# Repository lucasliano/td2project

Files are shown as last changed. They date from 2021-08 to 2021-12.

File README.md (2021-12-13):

<!-- Badged -->





> :warning: **Work In Progress** :warning:

<!-- PROJECT LOGO -->
<br />
<p align="center">
  <a href="https://github.com/lucasliano/td2project">
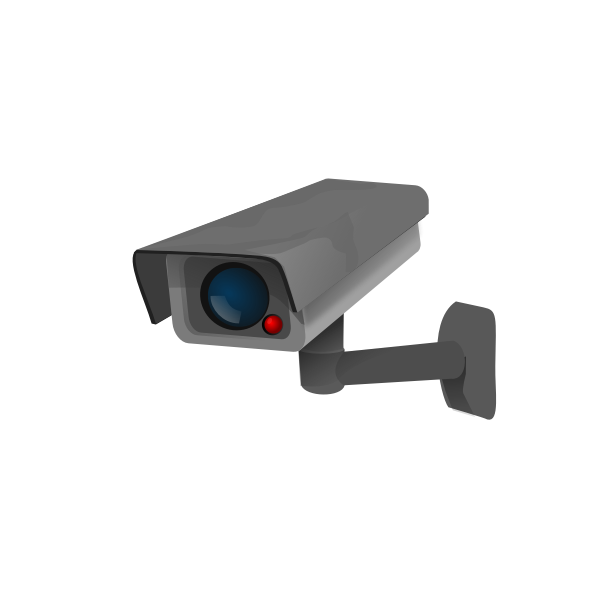
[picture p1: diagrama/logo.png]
    
  </a>

  <h3 align="center">Security Alarm System</h3>
  
  <p align="center">
    This security system project is the final assignment of the digital technics II subjects at Universidad Tecnológica Nacional.
    <br />
    <a href="https://github.com/lucasliano/td2project"><strong>Explore the docs »</strong></a>
    <br />
    <br />
    <a href="https://github.com/lucasliano/td2project">View Demo</a>
    ·
    <a href="https://github.com/lucasliano/td2project/issues">Report Bug</a>
    ·
    <a href="https://github.com/lucasliano/td2project/issues">Request Feature</a>
  </p>
</p>

<!-- TABLE OF CONTENTS -->
<details open="open">
  <summary><h2 style="display: inline-block">Table of Contents</h2></summary>
  <ol>
    <li>
      <a href="#about-the-project">About The Project</a>
      <ol>
      <li><a href="#system-diagram">System Diagram</a></li>
      <li><a href="#main-board-pcb-and-schematics">Main Board PCB and Schematics</a></li>
      <li><a href="#equipment">Equipment</a></li>
    </ol>
    </li>
    <li><a href="#authors">Authors</a></li>
    <li><a href="#license">License</a></li>
    <li><a href="#contact">Contact</a></li>
  </ol>
</details>

## About The Project

The main idea of this project is to build a systems which allows you to detect motion in different zones within your home.  

The activation/deactivation of the system is meant to be controlled using an android app or directly trough the front keyboard. At the same time, it would be possible to configure the system to deactivate the alarm in presence of a known RFID card.

Should an error occurred, a notification will be sent to the mobile device and it will be logged into the internal EEPROM memory. The system also takes into account possible disconnections from the power supply. 

#### System Diagram
<p align="center">
  <a href="https://github.com/lucasliano/td2project">
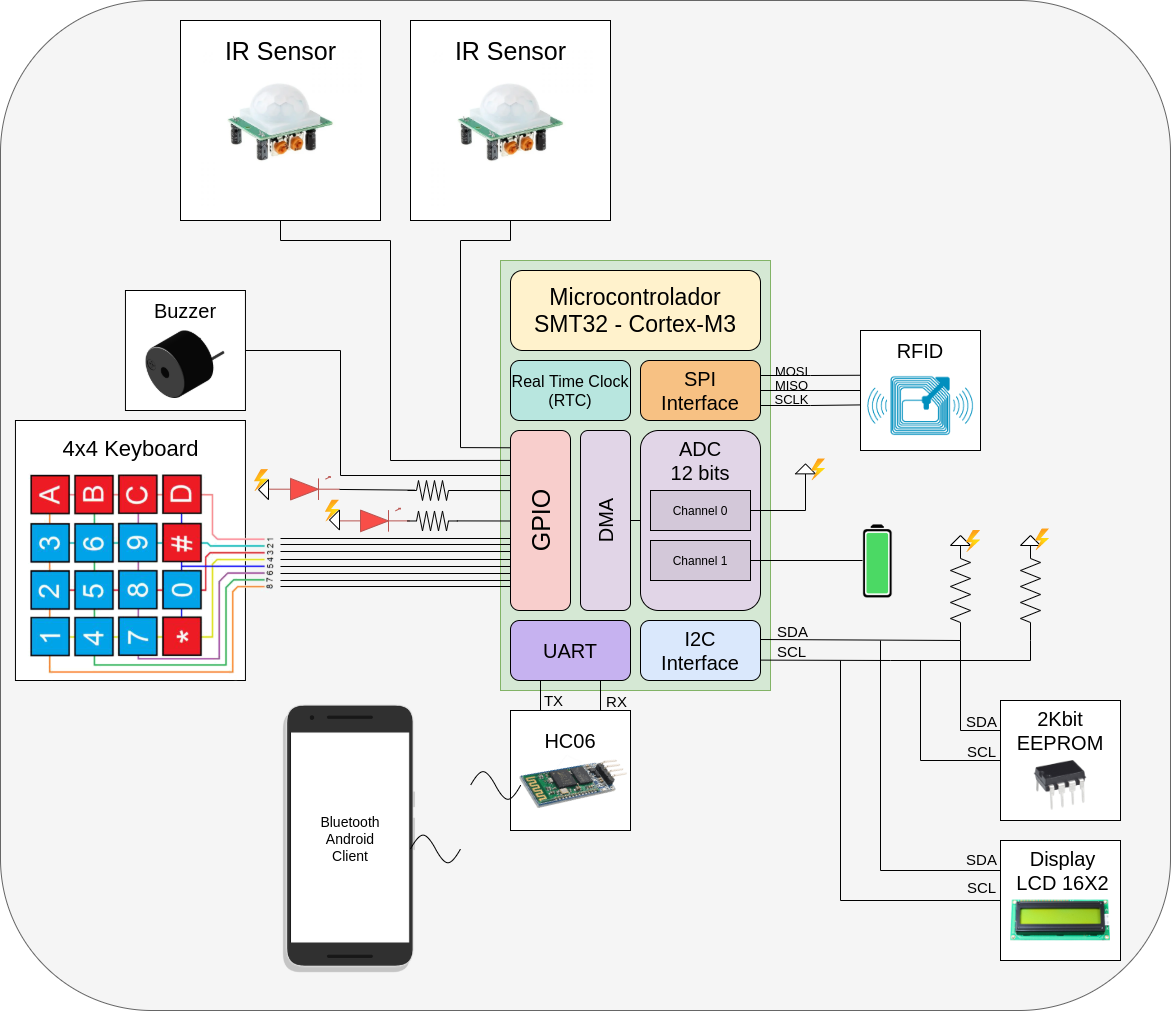
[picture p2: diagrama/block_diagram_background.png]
Diagram
    
  </a>
</p>

#### Memory Map
This section describes the EEPROM memory organization. Each section provides critical information to the system. All the registers stored in the _Logs Block_ will be available through the android app.

<p align="center">
  <a href="https://github.com/lucasliano/td2project">
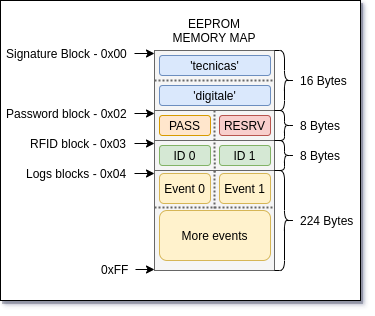
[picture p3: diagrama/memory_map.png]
Memory map
    
  </a>
</p>

### Main Board PCB and Schematics

#### Schematics
The main board includes a battery charger and power supply source administrator. You will find this schematic in a PDF file in the ``` PCB_files_kicad ``` folder.

<p align="center">
  <a href="https://github.com/lucasliano/td2project/blob/main/PCB/Schematic%20v1.7.pdf">
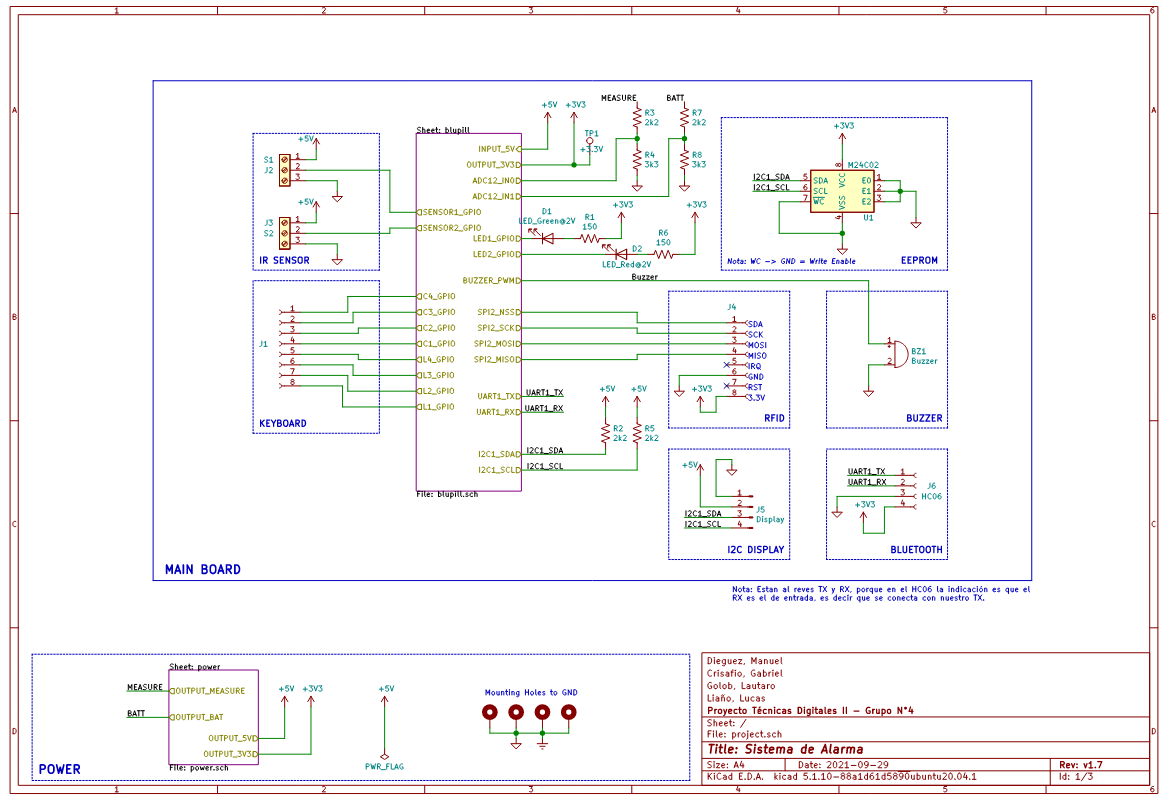
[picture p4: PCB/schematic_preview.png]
Schematic
    
  </a>
</p>

#### PCB
<p align="center">
  <a href="https://github.com/lucasliano/td2project/tree/main/PCB/project">
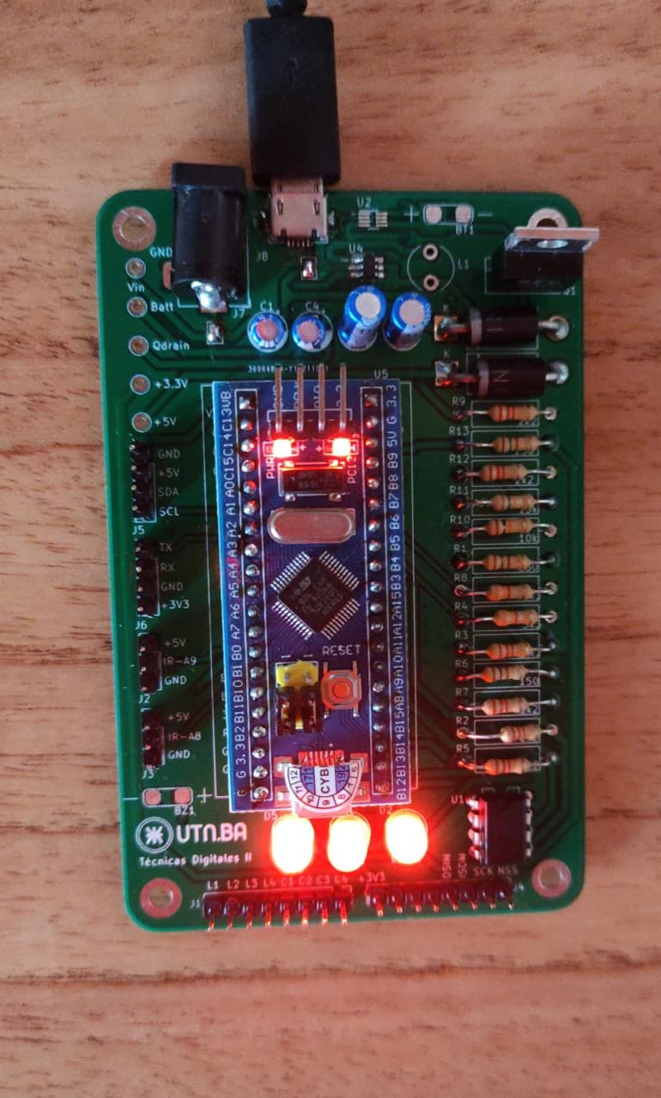
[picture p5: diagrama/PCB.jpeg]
PCB
    
  </a>
</p>

## Requirements

```
sudo apt-get install python-dev libbluetooth-dev
```

<!-- Authors -->
## Authors
* Liaño, Lucas
* Dieguez, Manuel
* Golob, Lautaro Francisco
* Crisafio, Gabriel

<!-- LICENSE -->
## License

Distributed under the GPL-3.0 License. See `LICENSE` for more information.

<!-- CONTACT -->
## Contact

Lucas Liaño - lliano@frba.utn.edu.ar

Repo Link: [https://github.com/lucasliano/td2project](https://github.com/lucasliano/td2project)

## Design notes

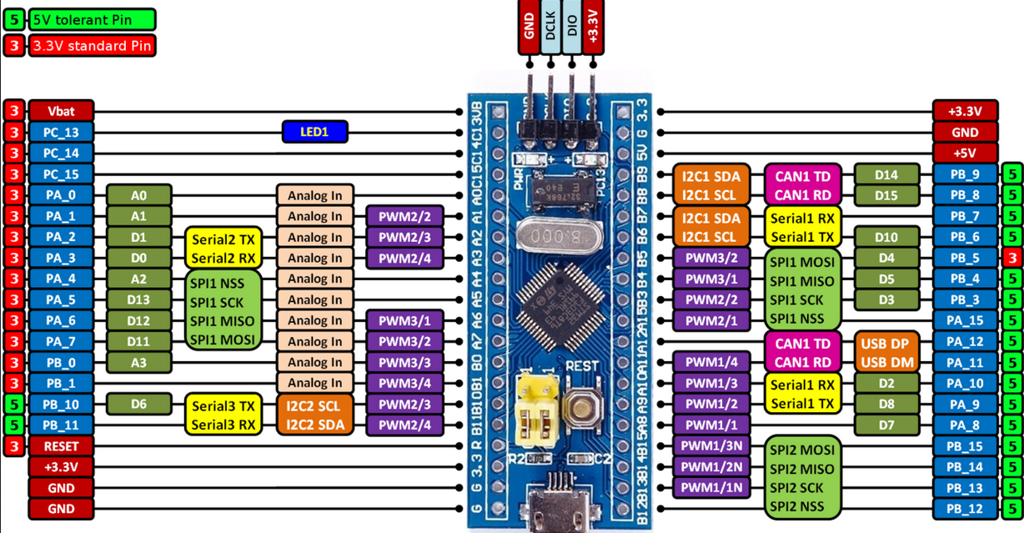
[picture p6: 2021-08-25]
PCB/Bluepill Pinout.png

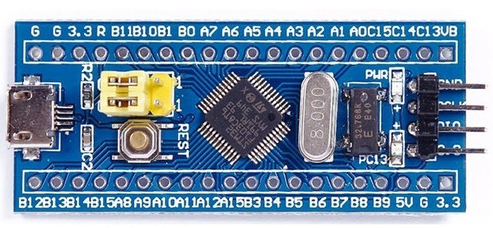
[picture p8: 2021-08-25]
diagrama/Bluepill.png

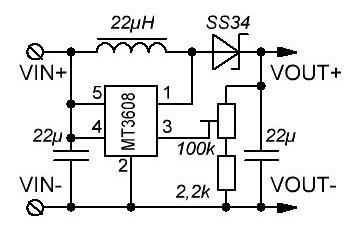
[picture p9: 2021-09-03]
PCB/project/MTcircuit.jpg

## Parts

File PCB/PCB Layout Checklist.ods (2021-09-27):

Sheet: Completa
# | Ubicación de componentes | Cumple / No cumple / No aplica
1 | Orientación consistente de componentes SMD
2 | Espacio para herramientas de retrabajo y extraccion de ICs
3 | Verificar componentes polarizados
4 | Utilizar grilla de 50 mil (o 1.25mm) para componentes THT y 20 mils (o 0.5mm) para SMD
5 | Verificar orientación de todos los conectores
6 | Verificar espacio mínimo entre cuerpo de componentes
7 | Capacitores de desacople (bypass) cerca de pines de alimentación de los IC
8 | Verificar terminadores en serie cercanos a la fuente
9 | Drivers I/O cercanos a donde las señales abandonan el PCB
10 | Pistas de alimentación y test points, todos etiquetados.
11 | Filtros EMI y RFI lo más cerca posible a puntos de entrada y salida en áreas blindadas. | No Aplica
12 | Verificar que los potenciómetros incrementan la cantidad controlada en sentido de las agujas del reloj. | No Aplica
13 | Verificar si los orificios de montaje deben estar aislados eléctricamente o no.
14 | Verificar distancia de seguridad de los orificios de montaje hacia otros componentes.
15 | Verificar factor de forma de los pads SMD.
16 | Fiduciales locales y en panel para ensamle automático. | No Aplica
17 | Distancia de seguridad suficiente para ICs con zócalo. | No Aplica
# | Ruteo/pistas | Cumple / No cumple / No aplica
18 | Comunes digitales y analógicos unidos en un solo punto. | No cumple
19 | Verificar pistas debajo de componentes ruidosos o sensibles.
20 | No ubicar vias debajo de resistores de metalfilm u otros componentes con aislación pobre.
21 | Verificar pistas susceptibles a puentes de soldadura.
22 | Verificar pistas sin conexión en un extremo, a menos que sea a propósito.
23 | Asegurar que el CAD unifica o no señales Vcc/Vdd y Vss/GND según lo requiera el diseño.
24 | Utilizar múltiples vías en pistas de alta corriente y/o baja impedancia. | No cumple
25 | Observar keepout de componentes y pistas.
26 | Utilizar planos de GND donde sea posible.
# | Dimensiones | Cumple / No cumple / No aplica
27 | Diámetro de orificios debe considerar el metalizado.
28 | Diámetro de orificios más grande que el diámetro de pata al menos en 10 mils.
29 | Ancho de texto en silkscreen 0.20mm o más.
30 | Pad al menos 0.4mm más grande que drill.
31 | Componentes ubicados al menos a 1mm del borde del PCB.
32 | Test point ubicados al menos a 5mm del borde del PCB.
33 | Pistas al menos a 0.5mm del borde del PCB.
34 | Tolerancia de drills especificada.
35 | Tolerancia de máscara antisoldante especificada.
36 | Tolerancia de pistas especificada.
37 | Tolerancia de serigrafía especificada.
38 | Ancho de pista suficiente para la corriente que conduce.
39 | Distancia suficiente entre pistas de alto voltaje. | No Aplica
# | Serigrafía (silkscreen) | Cumple / No cumple / No aplica
40 | Evitar serigrafía sobre vías u orificios.
41 | Todos los textos y leyendas legibles en una o dos direcciones.
42 | Logo de la compañía en serigrafía y/o en cobre (logo de la facultad en nuestro caso)
43 | Nota de copyright en PCB.
44 | Fecha en PCB.
45 | Número de parte en PCB. (en nuesto caso TP1/TP2, etc) | No cumple
46 | Revisión del PCB en serigrafía. (v1.0 o R01)
47 | Espacio para revisión de montaje en serigrafía. (ASSY)
48 | Espacio para número de serie en serigrafía. (S/N) | No cumple
49 | Ubicar todo el texto de la serigrafía de manera tal que sea legible cuando los componentes están montados.
50 | Todos los ICs deben tener el pin 1 debidamente marcado y visible con el IC instalado.
51 | ICs de muchos pines deberían tener los pines extremos numerados para facilitar su identificación. | No cumple
52 | Marcas cada 5 o 10 pines en ICs o conectores de muchos pines para facilitar su identificación. | No Aplica
# | Otros | Cumple / No cumple / No aplica
53 | Utilizar DRC y ERC habilitados en el CAD. (chequeo de errores en esquemático y PCB)
54 | Tomar las precauciones necesarias en circuitos de alta frecuencia. | No Aplica
55 | Colocar conectores y pines extra en prototipos para pruebas, por si es necesario. | No cumple
56 | Verificar dimensiones y formas de orificios en conectores raros (rectangulares, ovalados).
57 | Verificar si la máscara antisoldante cubre o no cubre las vías.
58 | No rutear ángulos agudos.
59 | Verificar profundidad de la máscara antisoldante. | No cumple
60 | Verificar el netlist manualmente o por inspección visual. | No cumple
61 | Verificar si el origen de orificios es un pad de referencia.
62 | Anotar en layer auxiliar ancho del PCB, material y espesor del cobre.
63 | Utilizar aislamiento térmico (thermal relief) en capas internas de distribución de alimentación. | No Aplica
64 | Verificar que las aperturas para pasta de estaño sean del tamaño adecuado. | No cumple
65 | Verificar si se permiten blind/buried vias en PCB multicapa. | No Aplica
66 | Definir correctamente el panelizado del PCB. | No Aplica
67 | Encapsulados metálicos de cristales de alta frecuencia deberían conectarse a GND. | No Aplica

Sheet: Reducida
# | Ubicación de componentes | Comentarios | Cumple / No cumple / No aplica
1 | Orientación consistente de componentes SMD
2 | Espacio para herramientas de retrabajo y extraccion de ICs
3 | Verificar componentes polarizados
4 | Utilizar grilla de 50 mil (o 1.25mm) para componentes THT y 20 mils (o 0.5mm) para SMD
5 | Verificar orientación de todos los conectores
6 | Verificar espacio mínimo entre cuerpo de componentes
7 | Capacitores de desacople (bypass) cerca de pines de alimentación de los IC
8 | Pistas de alimentación y test points, todos etiquetados.
9 | Verificar que los potenciómetros incrementar la cantidad controlada en sentido de las agujas del reloj.
10 | Verificar distancia de seguridad de los orificios de montaje hacia otros componentes.
11 | Fiduciales locales y en panel para ensamle automático.
# | Ruteo/pistas | Comentarios | Cumple / No cumple / No aplica
12 | Verificar pistas debajo de componentes ruidosos o sensibles.
13 | Verificar pistas sin conexión en un extremo, a menos que sea a propósito.
14 | Utilizar múltiples vías en pistas de alta corriente y/o baja impedancia.
15 | Observar keepout de componentes y pistas.
16 | Utilizar planos de GND donde sea posible.
# | Dimensiones | Comentarios | Cumple / No cumple / No aplica
17 | Ancho de texto en silkscreen 0.20mm o más.
18 | Componentes ubicados al menos a 1mm del borde del PCB.
19 | Test point ubicados al menos a 5mm del borde del PCB.
20 | Pistas al menos a 0.5mm del borde del PCB.
21 | Ancho de pista suficiente para la corriente que conduce.
# | Serigrafía (silkscreen) | Comentarios | Cumple / No cumple / No aplica
22 | Evitar serigrafía sobre vías u orificios.
23 | Todos los textos y leyendas legibles en una o dos direcciones.
24 | Logo de la compañía en serigrafía y/o en cobre (logo de la facultad en nuestro caso)
25 | Nota de copyright en PCB.
26 | Fecha en PCB.
27 | Número de parte en PCB. (en nuesto caso TP1/TP2, etc)
28 | Revisión del PCB en serigrafía. (v1.0 o R01)
29 | Espacio para revisión de montaje en serigrafía. (ASSY)
30 | Espacio para número de serie en serigrafía. (S/N)
31 | Ubicar todo el texto de la serigrafía de manera tal que sea legible cuando los componentes están montados.
32 | Todos los ICs deben tener el pin 1 debidamente marcado y visible con el IC instalado.
33 | ICs de muchos pines deberían tener los pines extremos numerados para facilitar su identificación.
34 | Marcas cada 5 o 10 pines en ICs o conectores de muchos pines para facilitar su identificación.
# | Otros | Comentarios | Cumple / No cumple / No aplica
35 | Utilizar DRC y ERC habilitados en el CAD. (chequeo de errores en esquemático y PCB)
36 | Verificar si la máscara antisoldante cubre o no cubre las vías.
37 | No rutear ángulos agudos.
38 | Anotar en layer auxiliar ancho del PCB, material y espesor del cobre.
39 | Utilizar aislamiento térmico (thermal relief) en capas internas de distribución de alimentación.
40 | Definir correctamente el panelizado del PCB.

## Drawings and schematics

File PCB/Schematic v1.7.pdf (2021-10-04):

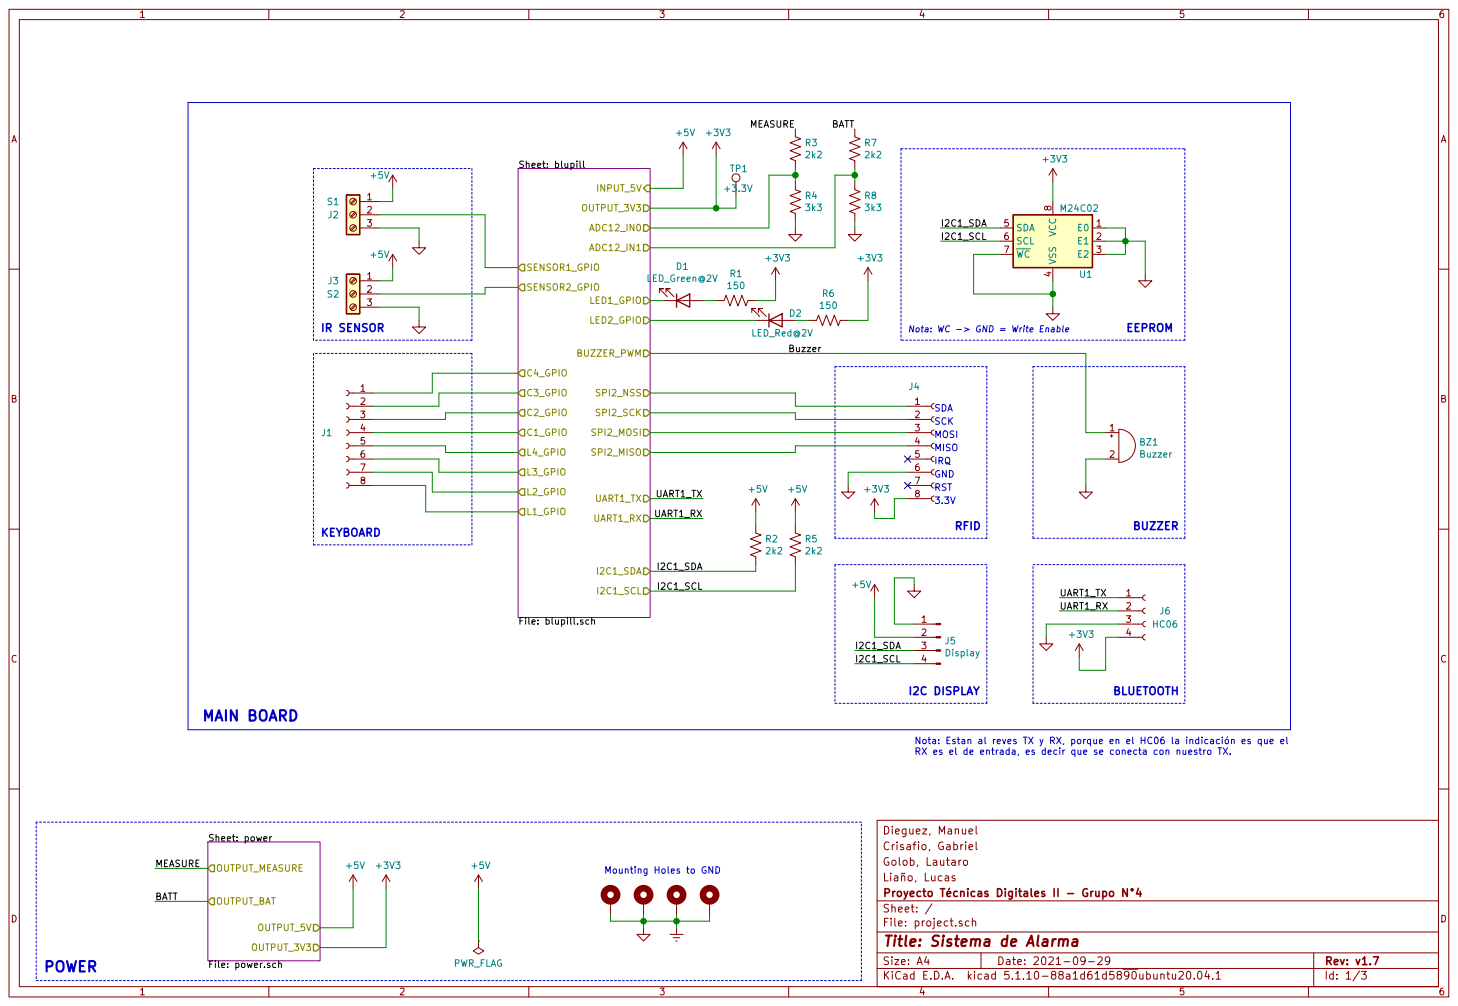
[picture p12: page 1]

4 SDA 5 SCL 6 WC 7 VCC

RX es el de entrada, es decir que se conecta con nuestro TX. BUZZER MAIN BOARD

Nota: Estan al reves TX y RX, porque en el HC06 la indicación es que el

Dieguez, Manuel
Crisafio, Gabriel
Golob, Lautaro
Liaño, Lucas
File: project.sch Sheet: / Proyecto Técnicas Digitales II - Grupo N°4

Id: 1/3 Title: Sistema de Alarma

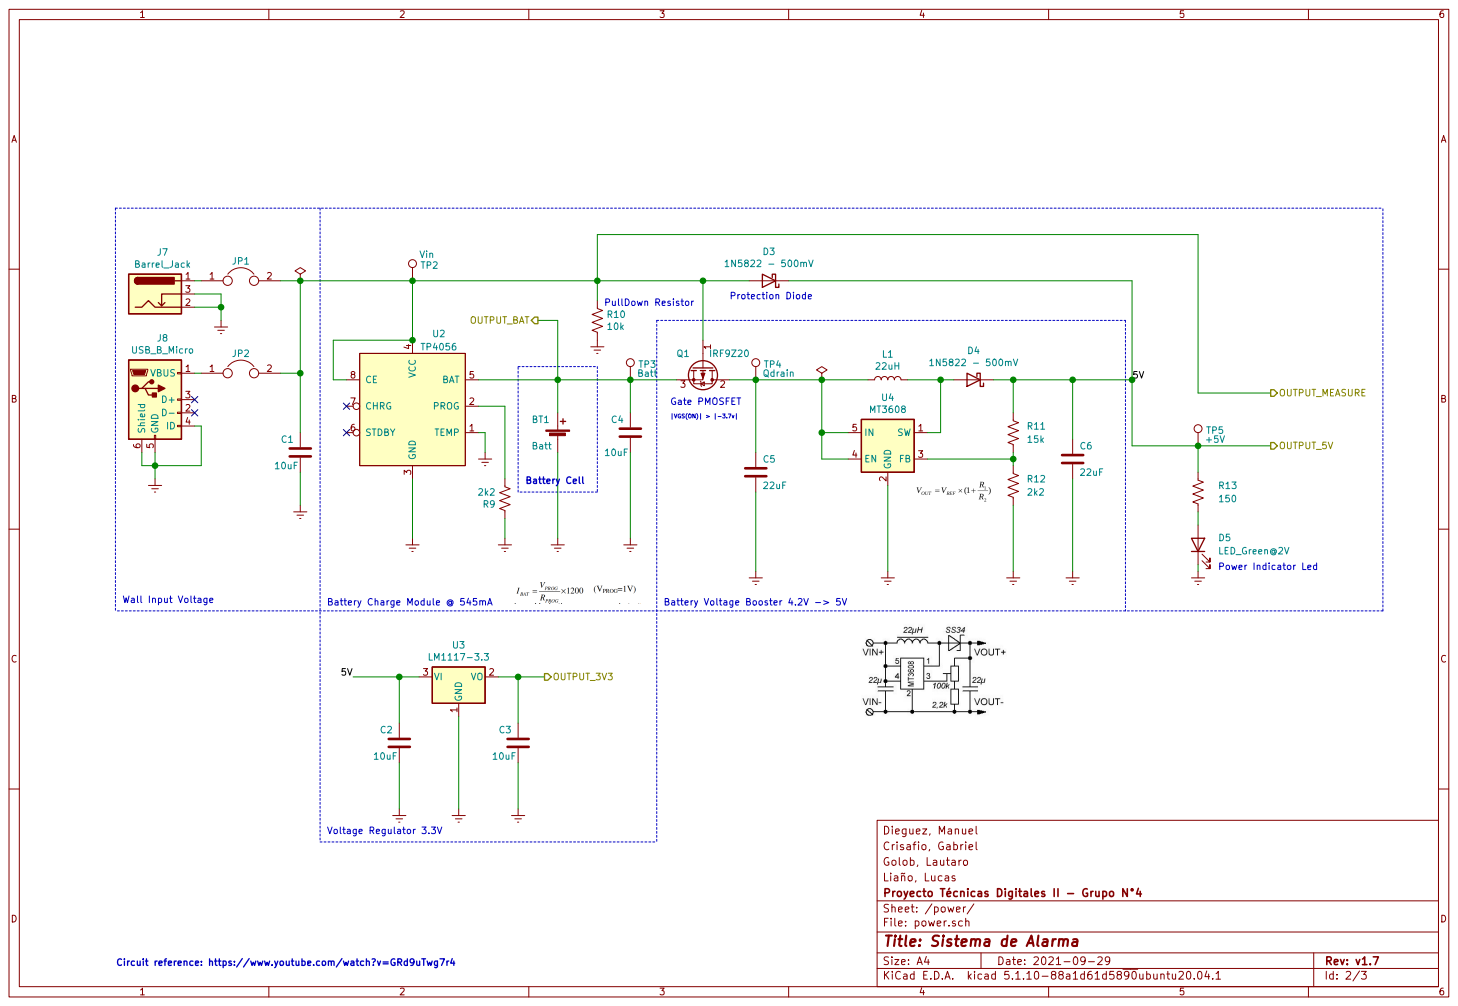
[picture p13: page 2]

4 BAT 5 STDBY 6 CHRG 7 CE 8 U2 TP4056 C4

Battery Cell

Dieguez, Manuel
Crisafio, Gabriel
Golob, Lautaro
Liaño, Lucas
Proyecto Técnicas Digitales II - Grupo N°4
Sheet: /power/
File: power.sch
Id: 2/3 Title: Sistema de Alarma

Circuit reference: https://www.youtube.com/watch?v=GRd9uTwg7r4

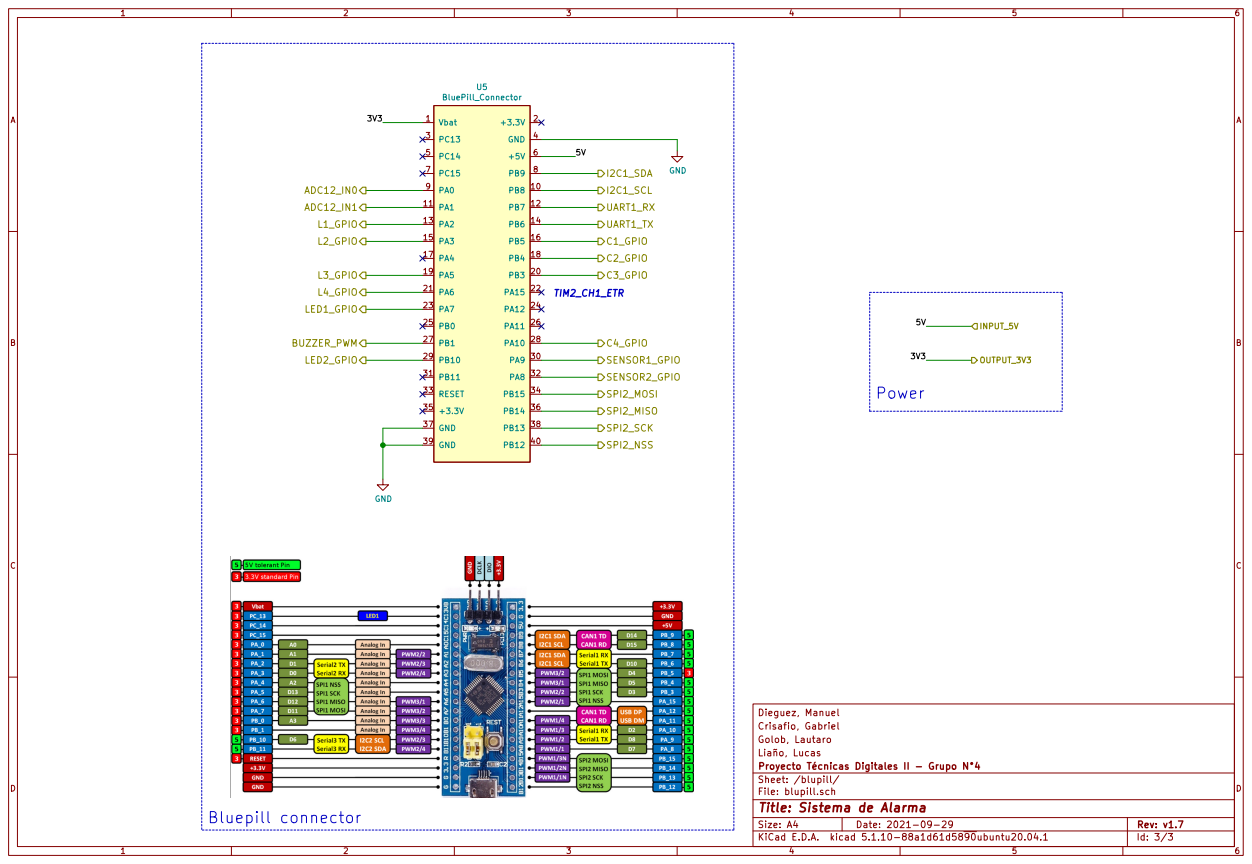
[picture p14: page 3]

Dieguez, Manuel
Crisafio, Gabriel
Golob, Lautaro
Liaño, Lucas
Proyecto Técnicas Digitales II - Grupo N°4
Sheet: /blupill/
File: blupill.sch
Id: 3/3 Title: Sistema de Alarma

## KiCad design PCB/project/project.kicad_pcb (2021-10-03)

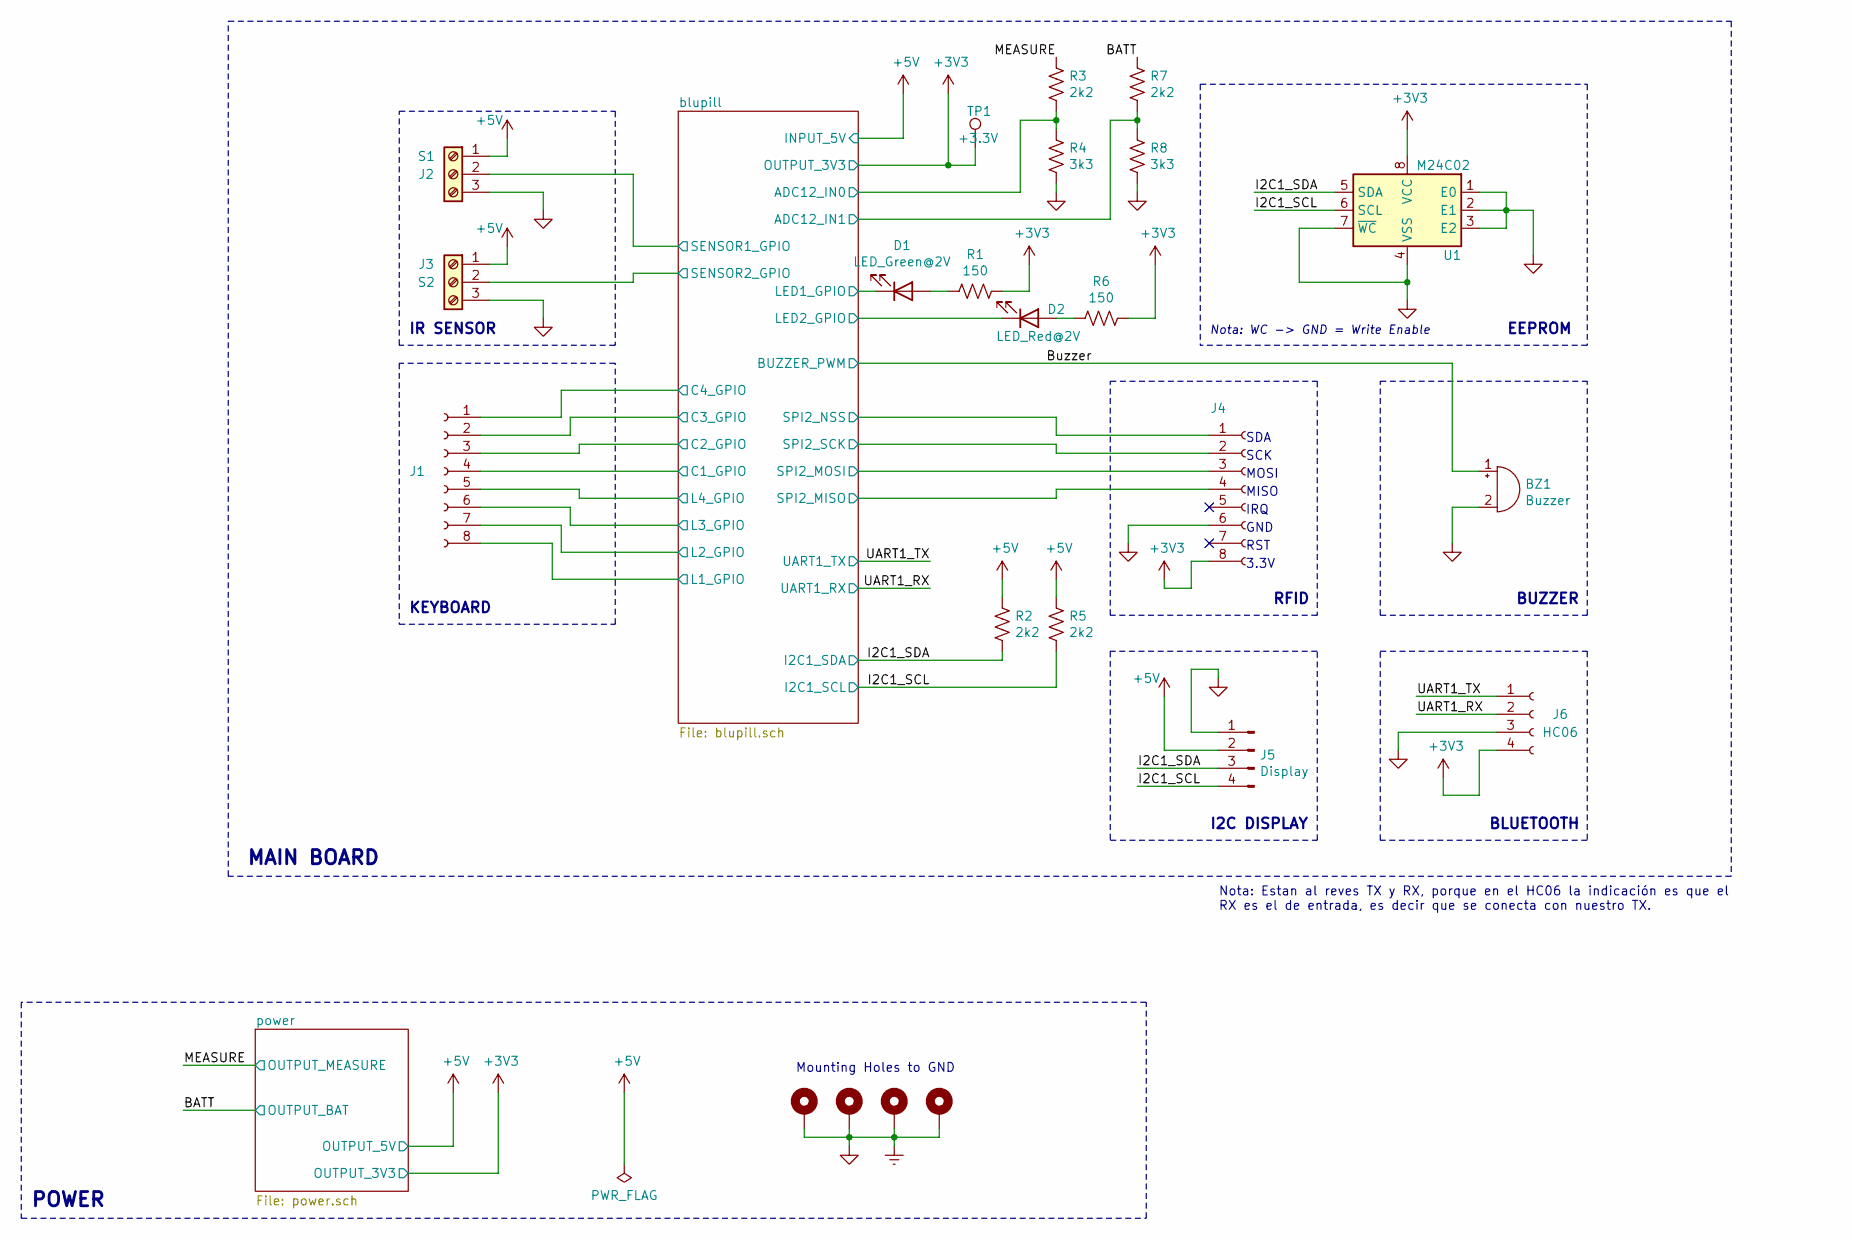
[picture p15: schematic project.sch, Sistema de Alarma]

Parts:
BZ1: Buzzer; Batt
D1: LED_Green@2V; LED_D5.0mm
D2: LED_Red@2V; LED_D5.0mm
H1, H2, H3, H4: MountingHole_Pad; MountingHole_3.2mm_M3_DIN965_Pad_TopBottom
J1, J4: Conn_01x08_Female; PinHeader_1x08_P2.54mm_Vertical
J2: S1; PinHeader_1x03_P2.54mm_Vertical
J3: S2; PinHeader_1x03_P2.54mm_Vertical
J5: Display; PinHeader_1x04_P2.54mm_Vertical
J6: HC06; PinHeader_1x04_P2.54mm_Vertical
R1, R6: 150; R_Axial_DIN0309_L9.0mm_D3.2mm_P12.70mm_Horizontal
R2, R3, R5, R7: 2k2; R_Axial_DIN0309_L9.0mm_D3.2mm_P12.70mm_Horizontal
R4, R8: 3k3; R_Axial_DIN0309_L9.0mm_D3.2mm_P12.70mm_Horizontal
TP1: +3.3V; TestPoint_THTPad_D2.0mm_Drill1.0mm
U1: M24C02; DIP-8_W7.62mm

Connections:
+3V3: J4.8, J6.4, R1.1, R6.1, TP1.1, U1.8 (VCC); also elsewhere on the board
+5V: J2.1, J3.1, J5.2, R2.1, R5.1; also elsewhere on the board
/BATT: R7.1; also elsewhere on the board
/Buzzer: BZ1.1 (-); also elsewhere on the board
/I2C1_SCL: J5.4, R5.2, U1.6 (SCL); also elsewhere on the board
/I2C1_SDA: J5.3, R2.2, U1.5 (SDA); also elsewhere on the board
/MEASURE: R3.1; also elsewhere on the board
/UART1_RX: J6.2; also elsewhere on the board
/UART1_TX: J6.1; also elsewhere on the board
/blupill/ADC12_IN0: R3.2, R4.1; also elsewhere on the board
/blupill/ADC12_IN1: R7.2, R8.1; also elsewhere on the board
/blupill/C1_GPIO: J1.4; also elsewhere on the board
/blupill/C2_GPIO: J1.3; also elsewhere on the board
/blupill/C3_GPIO: J1.2; also elsewhere on the board
/blupill/C4_GPIO: J1.1; also elsewhere on the board
/blupill/L1_GPIO: J1.8; also elsewhere on the board
/blupill/L2_GPIO: J1.7; also elsewhere on the board
/blupill/L3_GPIO: J1.6; also elsewhere on the board
/blupill/L4_GPIO: J1.5; also elsewhere on the board
/blupill/LED1_GPIO: D1.1 (K); also elsewhere on the board
/blupill/LED2_GPIO: D2.1 (K); also elsewhere on the board
/blupill/SENSOR1_GPIO: J2.2; also elsewhere on the board
/blupill/SENSOR2_GPIO: J3.2; also elsewhere on the board
/blupill/SPI2_MISO: J4.4; also elsewhere on the board
/blupill/SPI2_MOSI: J4.3; also elsewhere on the board
/blupill/SPI2_NSS: J4.1; also elsewhere on the board
/blupill/SPI2_SCK: J4.2; also elsewhere on the board
Earth: BZ1.2 (+), H1.1, H2.1, H3.1, H4.1, J2.3, J3.3, J4.6, J5.1, J6.3, R4.2, R8.2, U1.1 (E0), U1.2 (E1), U1.3 (E2), U1.4 (VSS), U1.7 (~WC); also elsewhere on the board
unnamed: D1.2 (A), R1.2
unnamed: D2.2 (A), R6.2

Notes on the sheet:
POWER
Mounting Holes to GND
KEYBOARD
IR SENSOR
I2C DISPLAY
RFID
SDA
SCK
MOSI
MISO
IRQ
GND
RST
3.3V
BUZZER
MAIN BOARD
BLUETOOTH
Nota: Estan al reves TX y RX, porque en el HC06 la indicación es que el RX es el de entrada, es decir que se conecta con nuestro TX.
EEPROM
Nota: WC -> GND = Write Enable

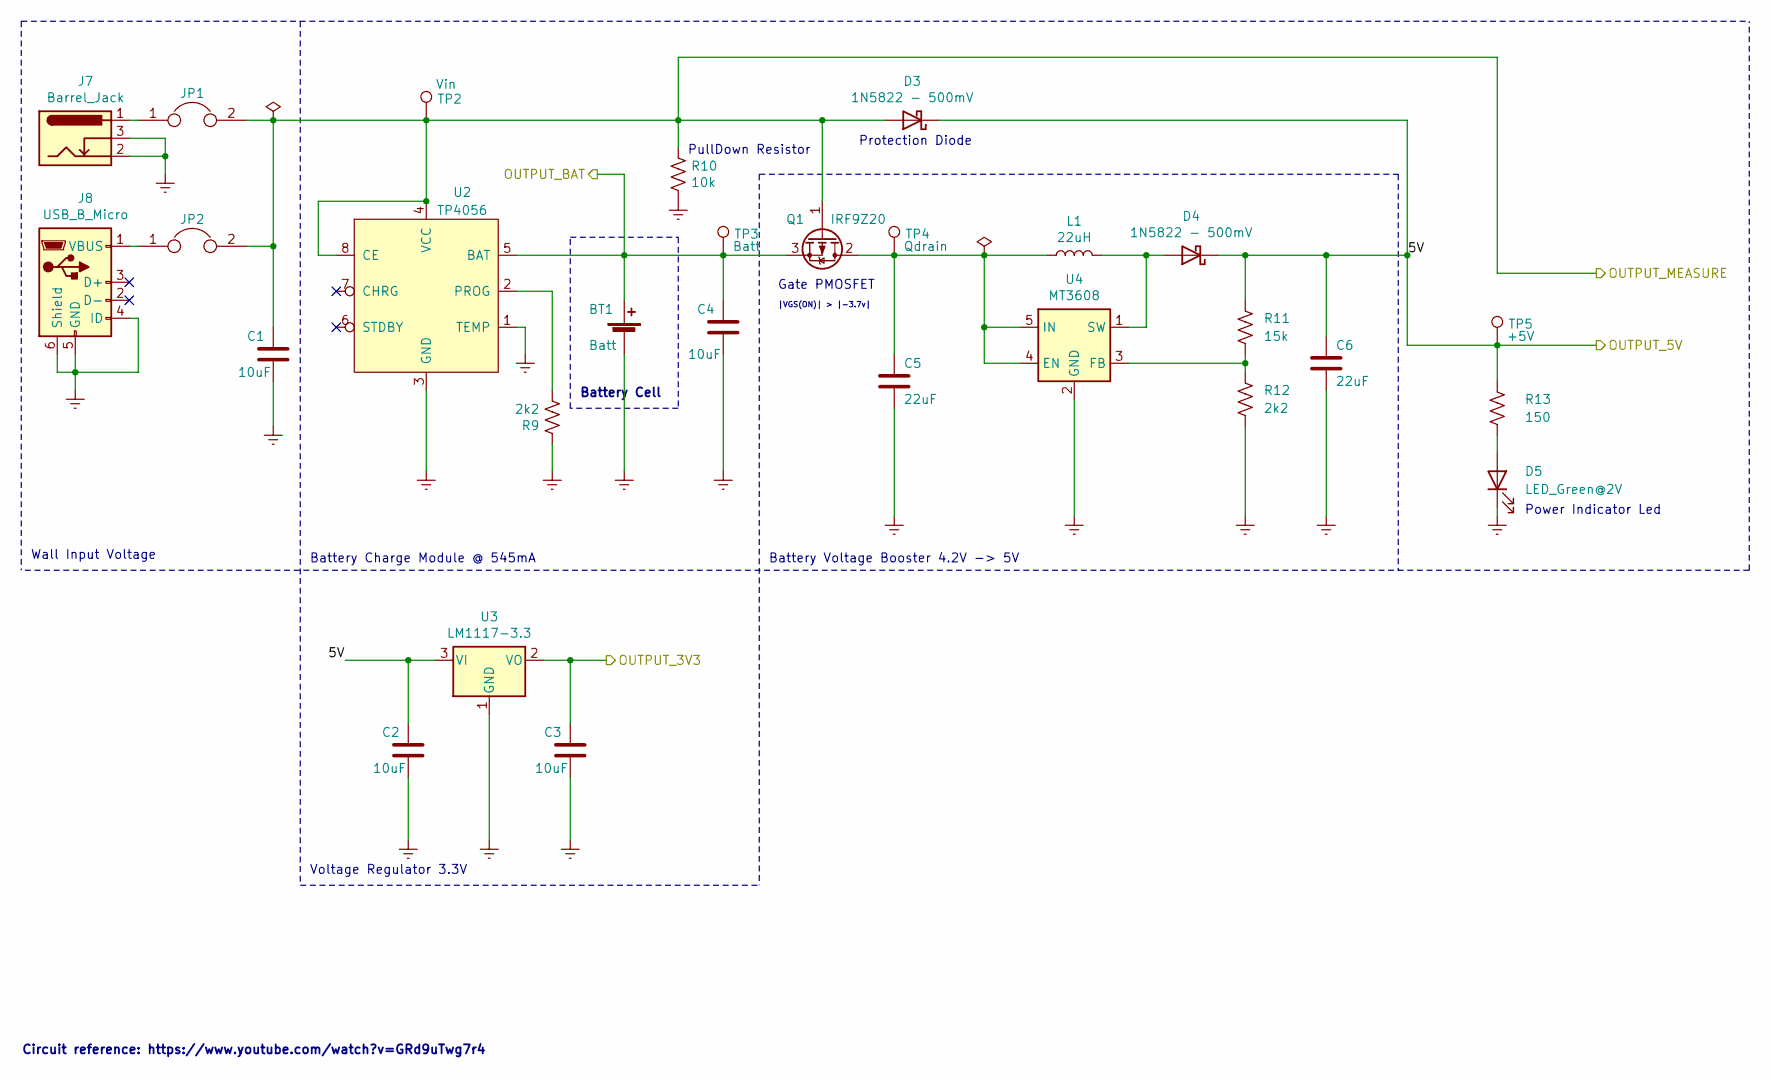
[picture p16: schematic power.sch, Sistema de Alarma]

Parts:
BT1: Batt
C1, C4: 10uF; CP_Radial_D5.0mm_P2.50mm
C2, C3: 10uF; C_0805_2012Metric_Pad1.18x1.45mm_HandSolder
C5, C6: 22uF; CP_Radial_D5.0mm_P2.50mm
D3, D4: 1N5822 - 500mV; D_DO-201AD_P15.24mm_Horizontal
D5: LED_Green@2V; LED_D5.0mm
J7: Barrel_Jack; BarrelJack_Horizontal
J8: USB_B_Micro; USB_Micro-B_Amphenol_10104110_Horizontal
JP1, JP2: Jumper; SolderJumper-2_P1.3mm_Open_Pad1.0x1.5mm
L1: 22uH; L_Radial_D6.0mm_P4.00mm
Q1: IRF9Z20; TO-220-3_Vertical; Mouser Number ver en electrocomponentes!
R9, R12: 2k2; R_Axial_DIN0309_L9.0mm_D3.2mm_P12.70mm_Horizontal
R10: 10k; R_Axial_DIN0309_L9.0mm_D3.2mm_P12.70mm_Horizontal
R11: 15k; R_Axial_DIN0309_L9.0mm_D3.2mm_P12.70mm_Horizontal
R13: 150; R_Axial_DIN0309_L9.0mm_D3.2mm_P12.70mm_Horizontal
TP2: Vin; TestPoint_THTPad_D2.0mm_Drill1.0mm
TP3: Batt; TestPoint_THTPad_D2.0mm_Drill1.0mm
TP4: Qdrain; TestPoint_THTPad_D2.0mm_Drill1.0mm
TP5: +5V; TestPoint_THTPad_D2.0mm_Drill1.0mm
U2: TP4056; SC-70-8_Handsoldering
U3: LM1117-3.3; SOT-223-3_TabPin2
U4: MT3608; SOT-23-6_Handsoldering

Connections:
+3V3: C3.1, U3.2 (VO); also elsewhere on the board
+5V: C2.1, C6.1, D3.1 (K), D4.1 (K), R11.1, R13.1, TP5.1, U3.3 (VI); also elsewhere on the board
/BATT: BT1.1 (+), C4.1, Q1.3 (S), TP3.1, U2.5 (BAT); also elsewhere on the board
/MEASURE: C1.1, D3.2 (A), JP1.2, JP2.2, Q1.1 (G), R10.1, TP2.1, U2.4 (VCC), U2.8 (CE); also elsewhere on the board
Earth: BT1.2 (-), C1.2, C2.2, C3.2, C4.2, C5.2, C6.2, D5.1 (K), J7.2, J7.3, J8.4 (ID), J8.5 (GND), J8.6 (Shield), R9.1, R10.2, R12.2, U2.1 (TEMP), U2.3 (GND), U3.1 (GND), U4.2 (GND); also elsewhere on the board
unnamed: C5.1, L1.1, Q1.2 (D), TP4.1, U4.4 (EN), U4.5 (IN)
unnamed: D4.2 (A), L1.2, U4.1 (SW)
unnamed: D5.2 (A), R13.2
unnamed: J7.1, JP1.1
unnamed: J8.1 (VBUS), JP2.1
unnamed: R9.2, U2.2 (PROG)
unnamed: R11.2, R12.1, U4.3 (FB)

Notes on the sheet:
Wall Input Voltage
Battery Cell
Battery Voltage Booster 4.2V -> 5V
Protection Diode
Gate PMOSFET
PullDown Resistor
Battery Charge Module @ 545mA
Power Indicator Led
|VGS(ON)| > |-3.7v|
Circuit reference: https://www.youtube.com/watch?v=GRd9uTwg7r4
Voltage Regulator 3.3V

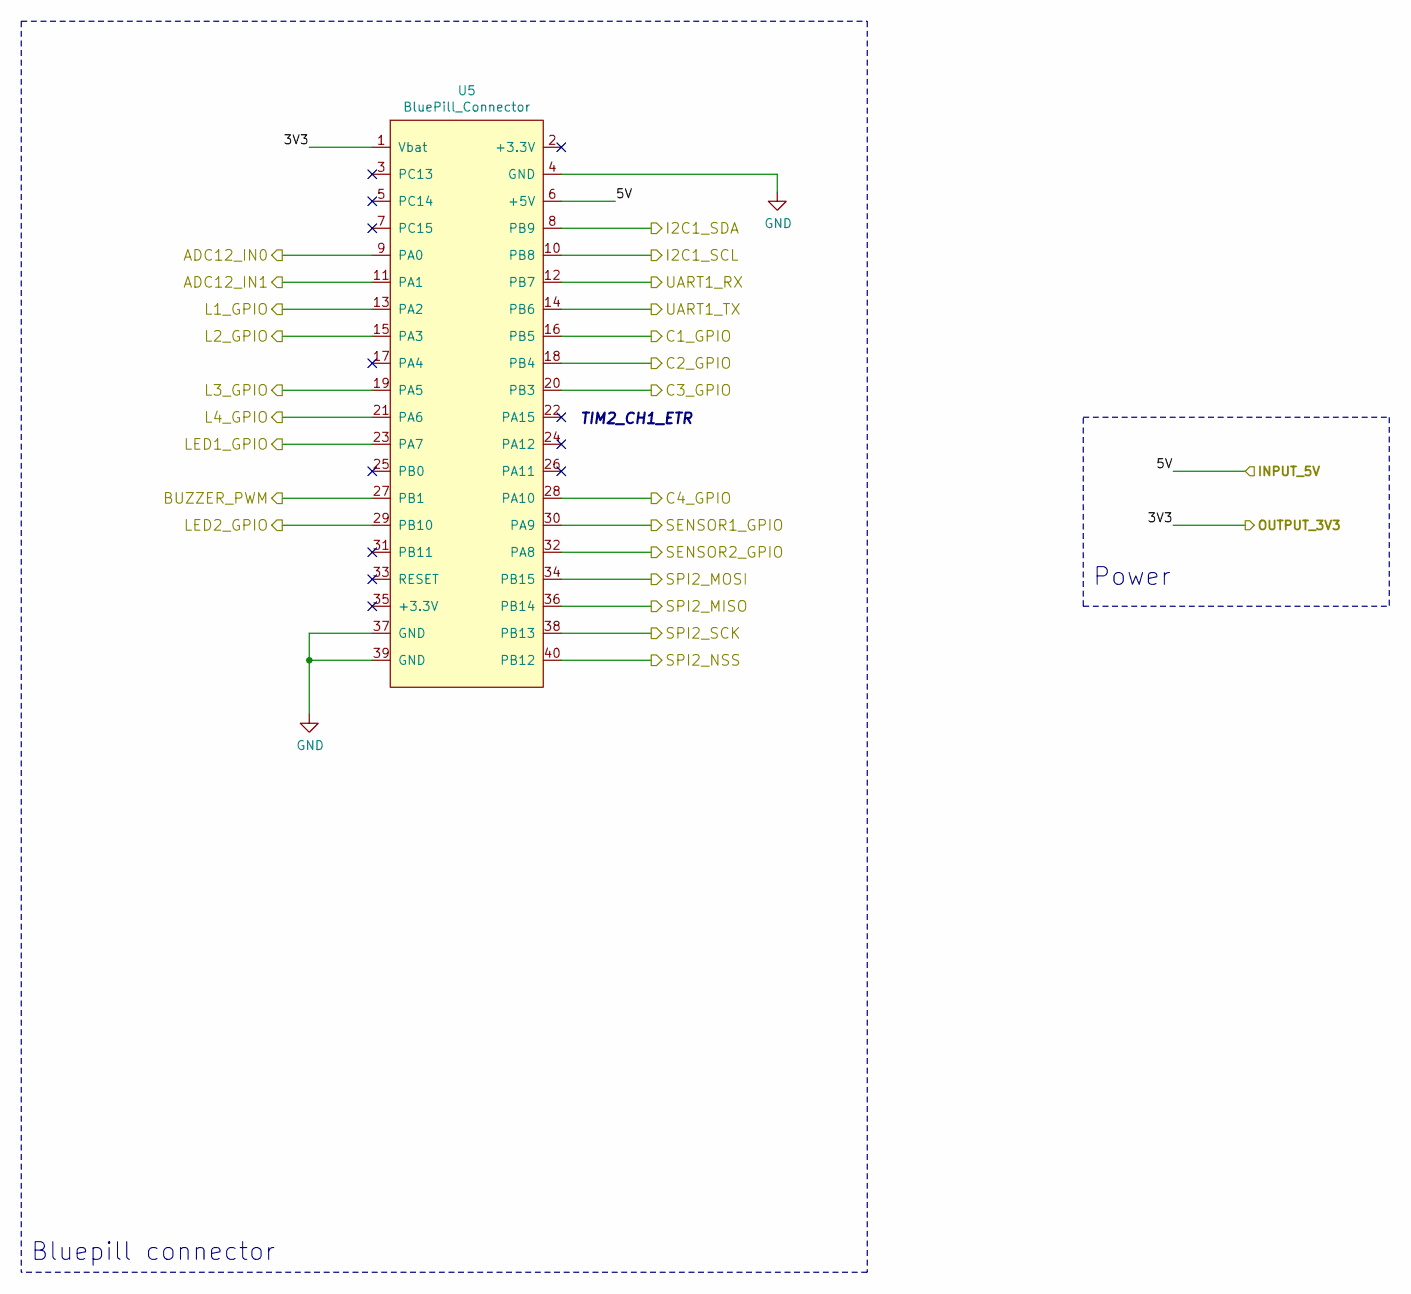
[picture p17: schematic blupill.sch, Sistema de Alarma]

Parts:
U5: BluePill_Connector; bluepill

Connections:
+3V3: U5.1 (Vbat); also elsewhere on the board
+5V: U5.6 (+5V); also elsewhere on the board
/Buzzer: U5.27 (PB1); also elsewhere on the board
/I2C1_SCL: U5.10 (PB8); also elsewhere on the board
/I2C1_SDA: U5.8 (PB9); also elsewhere on the board
/UART1_RX: U5.12 (PB7); also elsewhere on the board
/UART1_TX: U5.14 (PB6); also elsewhere on the board
/blupill/ADC12_IN0: U5.9 (PA0); also elsewhere on the board
/blupill/ADC12_IN1: U5.11 (PA1); also elsewhere on the board
/blupill/C1_GPIO: U5.16 (PB5); also elsewhere on the board
/blupill/C2_GPIO: U5.18 (PB4); also elsewhere on the board
/blupill/C3_GPIO: U5.20 (PB3); also elsewhere on the board
/blupill/C4_GPIO: U5.28 (PA10); also elsewhere on the board
/blupill/L1_GPIO: U5.13 (PA2); also elsewhere on the board
/blupill/L2_GPIO: U5.15 (PA3); also elsewhere on the board
/blupill/L3_GPIO: U5.19 (PA5); also elsewhere on the board
/blupill/L4_GPIO: U5.21 (PA6); also elsewhere on the board
/blupill/LED1_GPIO: U5.23 (PA7); also elsewhere on the board
/blupill/LED2_GPIO: U5.29 (PB10); also elsewhere on the board
/blupill/SENSOR1_GPIO: U5.30 (PA9); also elsewhere on the board
/blupill/SENSOR2_GPIO: U5.32 (PA8); also elsewhere on the board
/blupill/SPI2_MISO: U5.36 (PB14); also elsewhere on the board
/blupill/SPI2_MOSI: U5.34 (PB15); also elsewhere on the board
/blupill/SPI2_NSS: U5.40 (PB12); also elsewhere on the board
/blupill/SPI2_SCK: U5.38 (PB13); also elsewhere on the board
Earth: U5.4 (GND), U5.37 (GND), U5.39 (GND); also elsewhere on the board

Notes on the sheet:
Bluepill connector
Power
TIM2_CH1_ETR

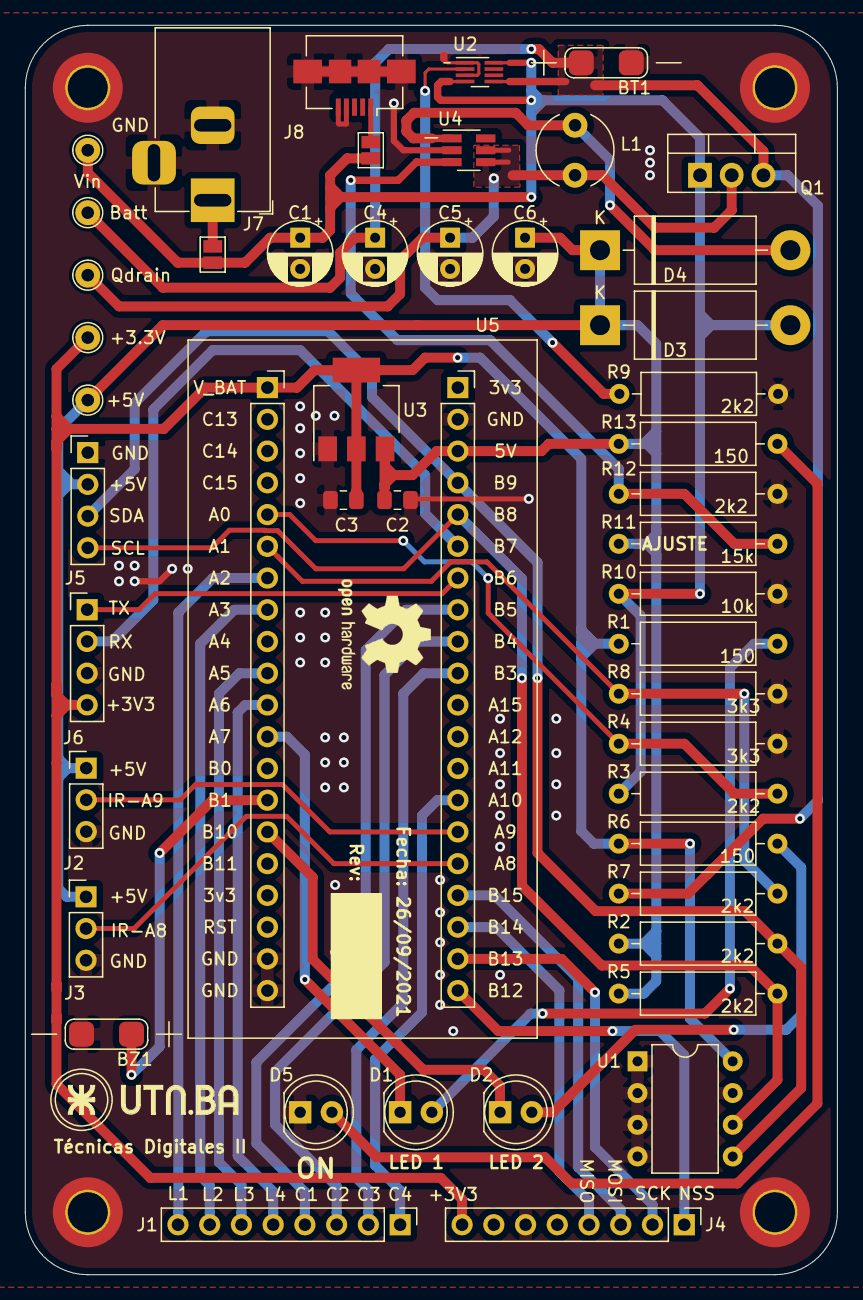
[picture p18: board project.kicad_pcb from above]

Board: 2 copper layers, 65.0 x 100.0 mm, 53 parts (0 on the bottom side), 37 nets.

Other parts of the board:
LogoUTN.BA-Letras: UTN.BA-Letras

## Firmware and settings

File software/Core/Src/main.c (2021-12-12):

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
/* Includes ------------------------------------------------------------------*/
#include "main.h"
#include "cmsis_os.h"

/* USER CODE BEGIN Includes */
#include <string.h>
#include <stdio.h>
#include "task.h"
#include "semphr.h"
#include "queue.h"

/* USER CODE END Includes */

ADC_HandleTypeDef hadc1;
DMA_HandleTypeDef hdma_adc1;

I2C_HandleTypeDef hi2c1;

RTC_HandleTypeDef hrtc;

SPI_HandleTypeDef hspi2;

UART_HandleTypeDef huart1;

osThreadId defaultTaskHandle;
void SystemClock_Config(void);
static void MX_GPIO_Init(void);
static void MX_DMA_Init(void);
static void MX_ADC1_Init(void);
static void MX_RTC_Init(void);
static void MX_USART1_UART_Init(void);
static void MX_I2C1_Init(void);
static void MX_SPI2_Init(void);
void StartDefaultTask(void const * argument);

/* USER CODE BEGIN PFP */
xSemaphoreHandle sem_state;
xSemaphoreHandle sem_clave;
xSemaphoreHandle sem_DMA;
xSemaphoreHandle sem_eeprom;

uint8_t clave_ok = 0;
uint8_t rfid_internal_state = WORKING_STATE; //ADDING_CARD_STATE;

uint16_t datos_adc_1[N_SAMPLES];
uint16_t datos_adc_2[N_SAMPLES];
uint16_t *datos_adc_dma, *datos_adc_uso;
medidas adc_buffer;
/* USER CODE END PFP */

/**
  * @brief  The application entry point.
  * @retval int
  */
int main(void)
{
  /* MCU Configuration--------------------------------------------------------*/

  /* Reset of all peripherals, Initializes the Flash interface and the Systick. */
  HAL_Init();

  /* Configure the system clock */
  SystemClock_Config();

  /* USER CODE BEGIN SysInit */
  HAL_NVIC_SetPriorityGrouping( NVIC_PRIORITYGROUP_4 );


  /* USER CODE END SysInit */

  /* Initialize all configured peripherals */
  MX_GPIO_Init();
  MX_DMA_Init();
  MX_ADC1_Init();
  MX_RTC_Init();
  MX_USART1_UART_Init();
  MX_I2C1_Init();
  MX_SPI2_Init();
  /* USER CODE BEGIN 2 */
  HAL_Delay(100);
  MFRC522_Init(&hspi2, SPI_NSS_GPIO_Port, SPI_NSS_Pin);
  led_init();
  init_teclado();
  init_eeprom(&hi2c1);
  rtc_init();
  lcd_init (&hi2c1);
  adc_init (&hadc1);
  serieFreeRTOS_inicializar(&huart1, 64);

  /* USER CODE END 2 */

  /* USER CODE BEGIN RTOS_MUTEX */
  /* add mutexes, ... */
  sem_state = xSemaphoreCreateMutex();
  sem_clave = xSemaphoreCreateMutex();
  sem_eeprom = xSemaphoreCreateMutex();
  sem_DMA = xSemaphoreCreateBinary();
  xSemaphoreTake(sem_DMA,0);
  /* USER CODE END RTOS_MUTEX */

  /* USER CODE BEGIN RTOS_SEMAPHORES */
  /* add semaphores, ... */
  /* USER CODE END RTOS_SEMAPHORES */

  /* USER CODE BEGIN RTOS_TIMERS */
  /* start timers, add new ones, ... */
  /* USER CODE END RTOS_TIMERS */

  /* USER CODE BEGIN RTOS_QUEUES */
  /* add queues, ... */
  /* USER CODE END RTOS_QUEUES */

  /* Create the thread(s) */
  /* definition and creation of defaultTask */
  osThreadDef(defaultTask, StartDefaultTask, osPriorityNormal, 0, 128);
  defaultTaskHandle = osThreadCreate(osThread(defaultTask), NULL);

  /* USER CODE BEGIN RTOS_THREADS */
  /* add threads, ... */
    if(xTaskCreate(checkear_teclado,
			  "checkear_teclado",
  			  configMINIMAL_STACK_SIZE,
			  NULL,
			  1,
			  NULL)!= pdPASS) Error_Handler();
    if(xTaskCreate(detectar_sensores,
  			  "detectar_sensores",
  			  configMINIMAL_STACK_SIZE,
  			  NULL,
  			  1,
  			  NULL)!= pdPASS) Error_Handler();
    if(xTaskCreate(lcd_update,
  			  "lcd_update",
  			  configMINIMAL_STACK_SIZE*4,
  			  NULL,
  			  1,
  			  NULL)!= pdPASS) Error_Handler();
    if(xTaskCreate(detectar_rfid,
			  "detectar_rfid",
  			  configMINIMAL_STACK_SIZE*4,
			  NULL,
			  1,
			  NULL)!= pdPASS) Error_Handler();
    if(xTaskCreate(tarea_conversiones,
  			  "tarea_conversiones",
  			  configMINIMAL_STACK_SIZE,
  			  NULL,
  			  1,
  			  NULL)!= pdPASS) Error_Handler();
    if(xTaskCreate(checkear_power_supply,
  			  "checkear_power_supply",
  			  configMINIMAL_STACK_SIZE,
  			  NULL,
  			  2,
  			  NULL)!= pdPASS) Error_Handler();
    if(xTaskCreate(tarea_serie,
			  "tarea_serie",
			  configMINIMAL_STACK_SIZE*4,
			  NULL,
			  3,
			  NULL)!= pdPASS) Error_Handler();




  /* USER CODE END RTOS_THREADS */

  /* Start scheduler */
  osKernelStart();

  /* We should never get here as control is now taken by the scheduler */
  /* Infinite loop */
  /* USER CODE BEGIN WHILE */
  while (1)
  {
    /* USER CODE END WHILE */

    /* USER CODE BEGIN 3 */
  }
  /* USER CODE END 3 */
}

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
/* USER CODE BEGIN Header_StartDefaultTask */
/**
  * @brief  Function implementing the defaultTask thread.
  * @param  argument: Not used
  * @retval None
  */
/* USER CODE END Header_StartDefaultTask */
void StartDefaultTask(void const * argument)
{
  /* USER CODE BEGIN 5 */
  /* Infinite loop */
  for(;;)
  {
    osDelay(1);
  }
  /* USER CODE END 5 */
}

/**
  * @brief  Period elapsed callback in non blocking mode
  * @note   This function is called  when TIM1 interrupt took place, inside
  * HAL_TIM_IRQHandler(). It makes a direct call to HAL_IncTick() to increment
  * a global variable "uwTick" used as application time base.
  * @param  htim : TIM handle
  * @retval None
  */
void HAL_TIM_PeriodElapsedCallback(TIM_HandleTypeDef *htim)
{
  if (htim->Instance == TIM1) {
    HAL_IncTick();
  }
}

/**
  * @brief  This function is executed in case of error occurrence.
  * @retval None
  */
void Error_Handler(void)
{
  /* USER CODE BEGIN Error_Handler_Debug */
  /* User can add his own implementation to report the HAL error return state */
  __disable_irq();
  while (1)
  {
	  toggle_led(LED_2);
	  for(uint32_t i = 0; i < 200000; i++);
  }
  /* USER CODE END Error_Handler_Debug */
}

#ifdef  USE_FULL_ASSERT
/**
  * @brief  Reports the name of the source file and the source line number
  *         where the assert_param error has occurred.
  * @param  file: pointer to the source file name
  * @param  line: assert_param error line source number
  * @retval None
  */
void assert_failed(uint8_t *file, uint32_t line)
{
  /* USER CODE BEGIN 6 */
  /* User can add his own implementation to report the file name and line number,
     ex: printf("Wrong parameters value: file %s on line %d\r\n", file, line) */
  /* USER CODE END 6 */
}
#endif /* USE_FULL_ASSERT */

/************************ (C) COPYRIGHT STMicroelectronics *****END OF FILE****/

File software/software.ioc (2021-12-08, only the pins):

Mcu.UserName=STM32F103C8Tx
PA0-WKUP.Signal=ADCx_IN0
PA1.Signal=ADCx_IN1
PA10.Signal=GPIO_Input
PA13.Signal=SYS_JTMS-SWDIO
PA14.Signal=SYS_JTCK-SWCLK
PA2.Signal=GPIO_Output
PA3.Signal=GPIO_Output
PA5.Signal=GPIO_Output
PA6.Signal=GPIO_Output
PA7.Signal=GPIO_Output
PA8.Signal=GPIO_Input
PA9.Signal=GPIO_Input
PB1.Signal=GPIO_Output
PB10.Signal=GPIO_Output
PB12.Signal=GPIO_Output
PB13.Signal=SPI2_SCK
PB14.Signal=SPI2_MISO
PB15.Signal=SPI2_MOSI
PB3.Signal=GPIO_Input
PB4.Signal=GPIO_Input
PB5.Signal=GPIO_Input
PB6.Signal=USART1_TX
PB7.Signal=USART1_RX
PB8.Signal=I2C1_SCL
PB9.Signal=I2C1_SDA
PC13-TAMPER-RTC.Signal=GPIO_Output
PD0-OSC_IN.Signal=RCC_OSC_IN
PD1-OSC_OUT.Signal=RCC_OSC_OUT

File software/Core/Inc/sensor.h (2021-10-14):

/*
 * sensor.h
 *
 *  Created on: Oct 6, 2021
 *      Author: manuel
 */

#ifndef INC_SENSOR_H_
#define INC_SENSOR_H_

#include "cmsis_os.h"
#include "stm32f1xx_hal.h"
#include "FreeRTOS.h"
#include "task.h"

#define Sensor1_Pin GPIO_PIN_9
#define Sensor1_GPIO_Port GPIOA

#define PUERTO_SENSOR1	GPIOA
#define PIN_SENSOR1		GPIO_PIN_9

#define PUERTO_SENSOR2	GPIOA
#define PIN_SENSOR2		GPIO_PIN_8

#define DEMORA_SENSOR	300 //ms

uint8_t leer_sensor(uint8_t);

#endif /* INC_SENSOR_H_ */

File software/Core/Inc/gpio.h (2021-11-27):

/*
 * gpio.h
 *
 *  Created on: Oct 23, 2021
 *      Author: lliano
 */

#ifndef INC_GPIO_H_
#define INC_GPIO_H_

#define LED_1 0
#define LED_2 1

#define LED_ON	GPIO_PIN_RESET
#define LED_OFF	GPIO_PIN_SET

void led_init(void);
void toggle_led(uint8_t led);
void start_buzzer(uint32_t ontime, uint32_t offtime, uint8_t ncycles);

#endif /* INC_GPIO_H_ */

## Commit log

2021-08-25 First push :D
    [blupill.sch, power.sch, power_and_blupill.sch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]
2021-08-25 Update README -> Adding Schematic link
2021-09-02 UART 7 data bits to 8 data bits
2021-09-03 PCB - Placing components
    [blupill.sch, power.sch, project.kicad_pcb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]
2021-09-03 PCB - Starting to route
    [power.sch, project.kicad_pcb]
2021-09-05 PCB v1.0 done
    [project.kicad_pcb]
2021-09-16 SCH version 1.3
    [blupill.sch, power.sch, project.kicad_pcb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]
2021-09-20 Lot of changes.. BOM was added and UTN logo too
    [PCB Layout Checklist.ods, power.sch, project.kicad_pcb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]
2021-09-23 Sche rev 1.4 - PCB rev 1.2
    [blupill.sch, power.sch, project.kicad_pcb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]
2021-09-27 Schematic v1.5 - PCB v1.3
    [PCB Layout Checklist.ods, blupill.sch, power.sch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]
2021-09-27 Schematic v1.6
    [blupill.sch, power.sch, project.kicad_pcb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]
2021-09-29 Schematic v1.7 - PCB v1.4
    [blupill.sch, power.sch, project.kicad_pcb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]
2021-09-30 PCB v1.5
    [project.kicad_pcb]
2021-09-30 Minor changes
    [blupill.sch, power.sch, project.kicad_pcb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]
2021-09-30 Version de fabricación!
    [project-B_Cu.gbr, project-B_Mask.gbr, project-B_Paste.gbr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]
2021-10-03 PCB folder renamed
    [PCB Layout Checklist.ods, blupill.sch, power.sch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]
2021-10-03 Error Handler in while(1)
    [main.c]
2021-10-03 PCB mini bug fix
    [project.kicad_pcb]
2021-10-04 Schematic pdf updated
2021-10-06 PCB images were added
2021-10-07 Intentando agregar RFID. Cambie configuraciones de CLK y de FreeRTOS (RAM que toma el SO)
2021-10-26 Working on eeprom. Not working yet
    [eeprom.c, main.c, tareas.c]
2021-10-26 i2c freq = 100kHz
2021-10-26 LCD drivers
2021-10-26 ADC kinda working
2021-11-04 working with project configuration (adding ADC w/ DMA)
2021-11-04 Adding ADC w/ DMA logic. Not working!
    [adc.c, adc.h, main.c]
2021-11-07 Fixing initial LEDs GPIO state
    [gpio.c, gpio.h, main.c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]
2021-11-08 Tarea para agregar tarjetas validas
2021-11-08 agregamos diagrama del mapa de memoria
2021-11-10 trying DMA w/ semaphore. Not working yet
    [adc.c, main.c]
2021-11-12 EEPROM routines were modify + ADC new idea
2021-11-27 ADC now working. STM project name was changed
2021-12-04 Improving IR sensors behaviour
2021-12-08 UART working
2021-12-10 UART improvements

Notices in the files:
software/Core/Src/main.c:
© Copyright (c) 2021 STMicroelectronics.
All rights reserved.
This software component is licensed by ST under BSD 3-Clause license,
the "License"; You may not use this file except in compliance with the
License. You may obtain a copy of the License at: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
